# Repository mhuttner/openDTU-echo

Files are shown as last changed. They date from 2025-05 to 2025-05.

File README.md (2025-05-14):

# openDTU Echo

PCB for openDTU onBattery

This PCB can be easily ordered from JLCPCB with assembly, but the ESP32-S3 and the Ebyte E49-900M20S module need to be soldered by hand.

## Features

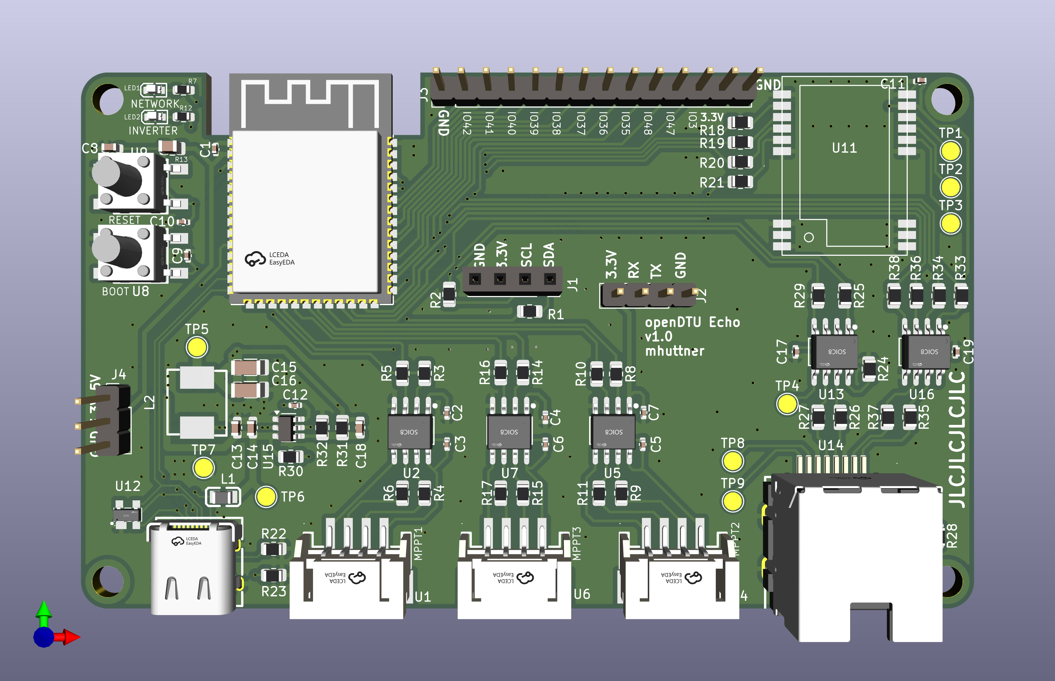
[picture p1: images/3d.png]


- ESP32-S3
- CMT2300A Chip in an Ebyte E49-900M20S module, NRF Chip is **not** supported
- Three ADUM1201 isolators with Ports for Victron VE.Direct Charge controllers / Smart Shunt
- SN65HVD230 CAN transceiver connected to RJ45 connector (Pin 4 and 5)
- ISL3178EIBZ RS485 transceiver connected to RJ45 connector (Pin 1 and 2)
- 3.3V Switching regulator based on the TPS54202DDC
- I2C Header for an OLED display

## Schematic

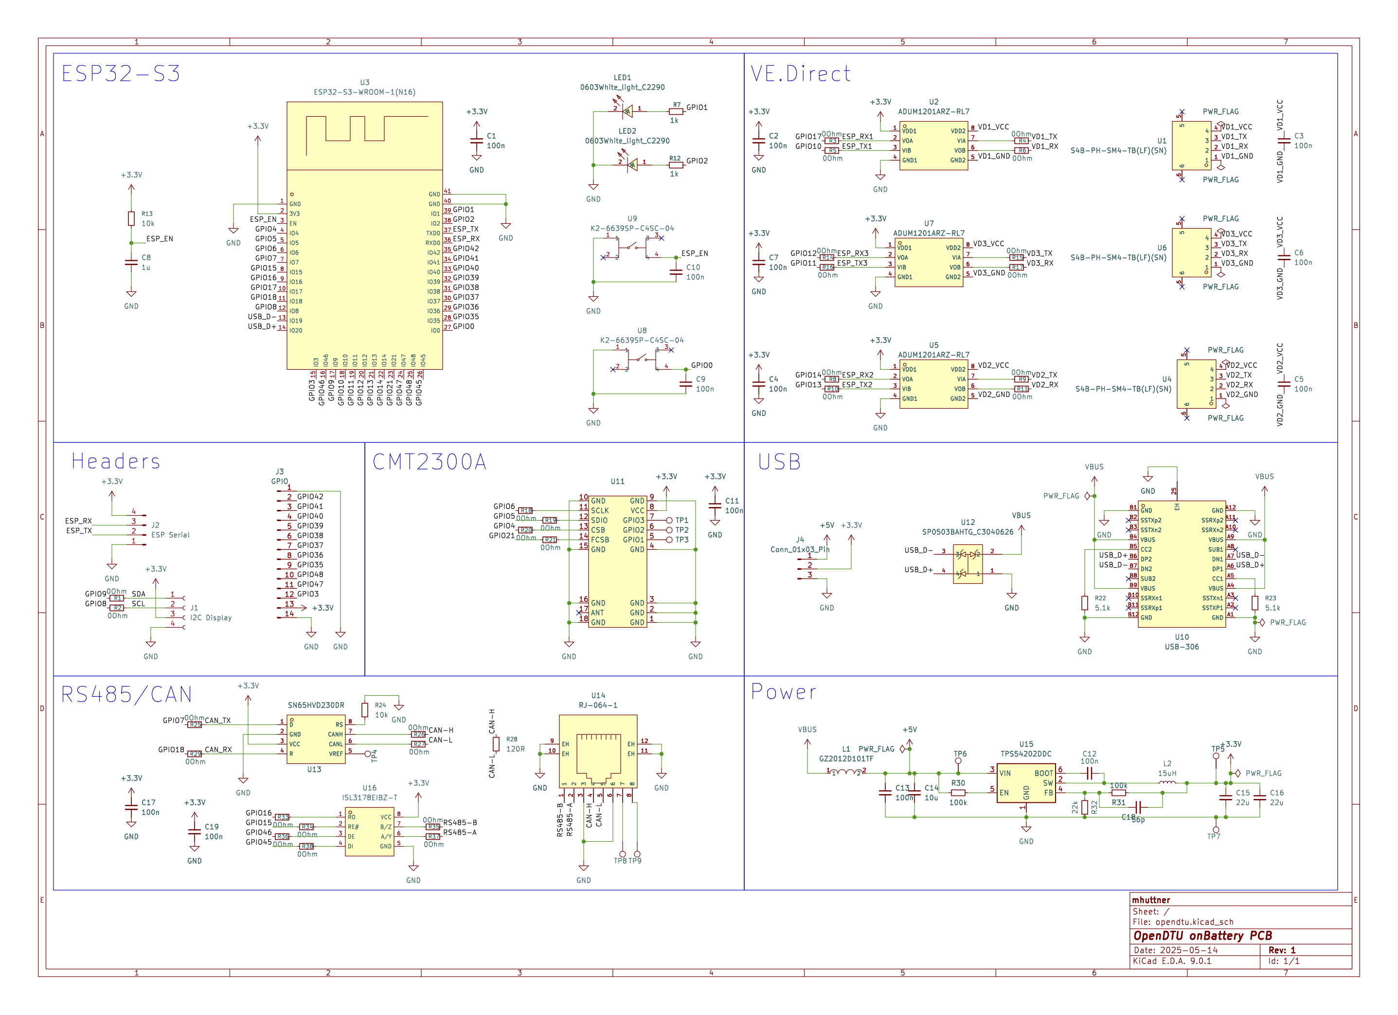
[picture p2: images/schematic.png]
Schematic


## PCB

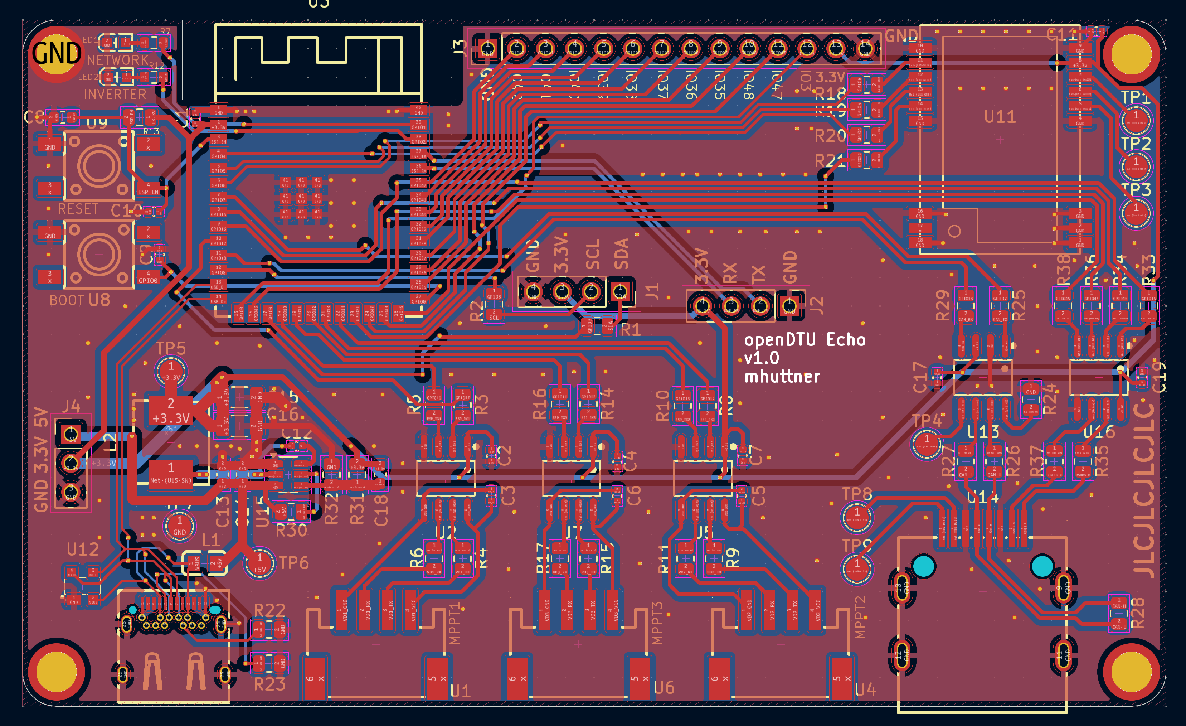
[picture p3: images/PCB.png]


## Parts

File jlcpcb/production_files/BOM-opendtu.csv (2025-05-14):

Comment | Designator | Footprint | LCSC | Quantity
GZ2012D101TF | L1 | L0805 | C1015 | 1
SN65HVD230DR | U13 | SOIC-8_L4.9-W3.9-P1.27-LS6.0-BL | C12084 | 1
22u | C15,C16 | C_1206_3216Metric | C12891 | 2
100n | C13 | C_0603_1608Metric | C14663 | 1
100k | R30,R31 | R_0805_2012Metric | C149504 | 2
100n | C1,C10,C11,C12,C17,C19,C2,C3,C4,C5,C6,C7,C9 | C_0402_1005Metric | C1525 | 13
1u | C8 | C_0603_1608Metric | C15849 | 1
56p | C18 | C_0603_1608Metric | C1676 | 1
10k | R13,R24 | C_0805_2012Metric | C17414 | 2
120R | R28 | R_0805_2012Metric | C17437 | 1
0Ohm | R1,R10,R11,R14,R15,R16,R17,R18,R19,R2,R20,R21,R25,R26,R27,R29,R3,R33,R34,R35,R36,R37,R38,R4,R5,R6,R8,R9 | R_0805_2012Metric | C17477 | 28
22k | R32 | R_0805_2012Metric | C17560 | 1
15uH | L2 | IND-SMD_L7.1-W6.6_SLO0618H | C182182 | 1
10u | C14 | C_0603_1608Metric | C19702 | 1
1k | R12,R7 | R_0603_1608Metric | C21190 | 2
0603White_light_C2290 | LED1,LED2 | LED0603-R-RD_WHITE | C2290 | 2
S4B-PH-SM4-TB(LF)(SN) | U1,U4,U6 | CONN-SMD_S4B-PH-SM4-TB-LF-SN | C265102 | 3
5.1k | R22,R23 | R_0805_2012Metric | C27834 | 2
ESP32-S3-WROOM-1(N16) | U3 | WIRELM-SMD_ESP32-S3-WROOM-1 | C2913199 | 1
SP0503BAHTG_C3040626 | U12 | SOT-143-4_L2.9-W1.3-P1.92-LS2.4-BL | C3040626 | 1
USB-306 | U10 | USB-TYPE-C-TH_USB-306. | C309338 | 1
ISL3178EIBZ-T | U16 | SOIC-8_L4.9-W3.9-P1.27-LS6.0-BL | C382015 | 1
RJ-064-1 | U14 | CONN-SMD_RJ-064 | C7205199 | 1
K2-6639SP-C4SC-04 | U8,U9 | KEY-SMD_4P-L6.0-W6.0-P3.90-LS9.0 | C83206 | 2
ADUM1201ARZ-RL7 | U2,U5,U7 | SOIC-8_L4.9-W3.9-P1.27-LS6.0-BL | C9669 | 3
TestPoint | TP1 | TestPoint_Pad_D2.0mm |  | 1
TestPoint | TP7 | TestPoint_Pad_D2.0mm |  | 1
TestPoint | TP9 | TestPoint_Pad_D2.0mm |  | 1
ESP Serial | J2 | PinHeader_1x04_P2.54mm_Vertical |  | 1
I2C Display | J1 | PinSocket_1x04_P2.54mm_Vertical |  | 1
TestPoint | TP3 | TestPoint_Pad_D2.0mm |  | 1
GPIO | J3 | PinHeader_1x14_P2.54mm_Vertical |  | 1
~ | U11 | E49-900M20S |  | 1
TestPoint | TP6 | TestPoint_Pad_D2.0mm |  | 1
Conn_01x03_Pin | J4 | PinHeader_1x03_P2.54mm_Vertical |  | 1
TestPoint | TP2 | TestPoint_Pad_D2.0mm |  | 1
TestPoint | TP4 | TestPoint_Pad_D2.0mm |  | 1
TestPoint | TP5 | TestPoint_Pad_D2.0mm |  | 1
TPS54202DDC | U15 | SOT-23-6 |  | 1
TestPoint | TP8 | TestPoint_Pad_D2.0mm |  | 1

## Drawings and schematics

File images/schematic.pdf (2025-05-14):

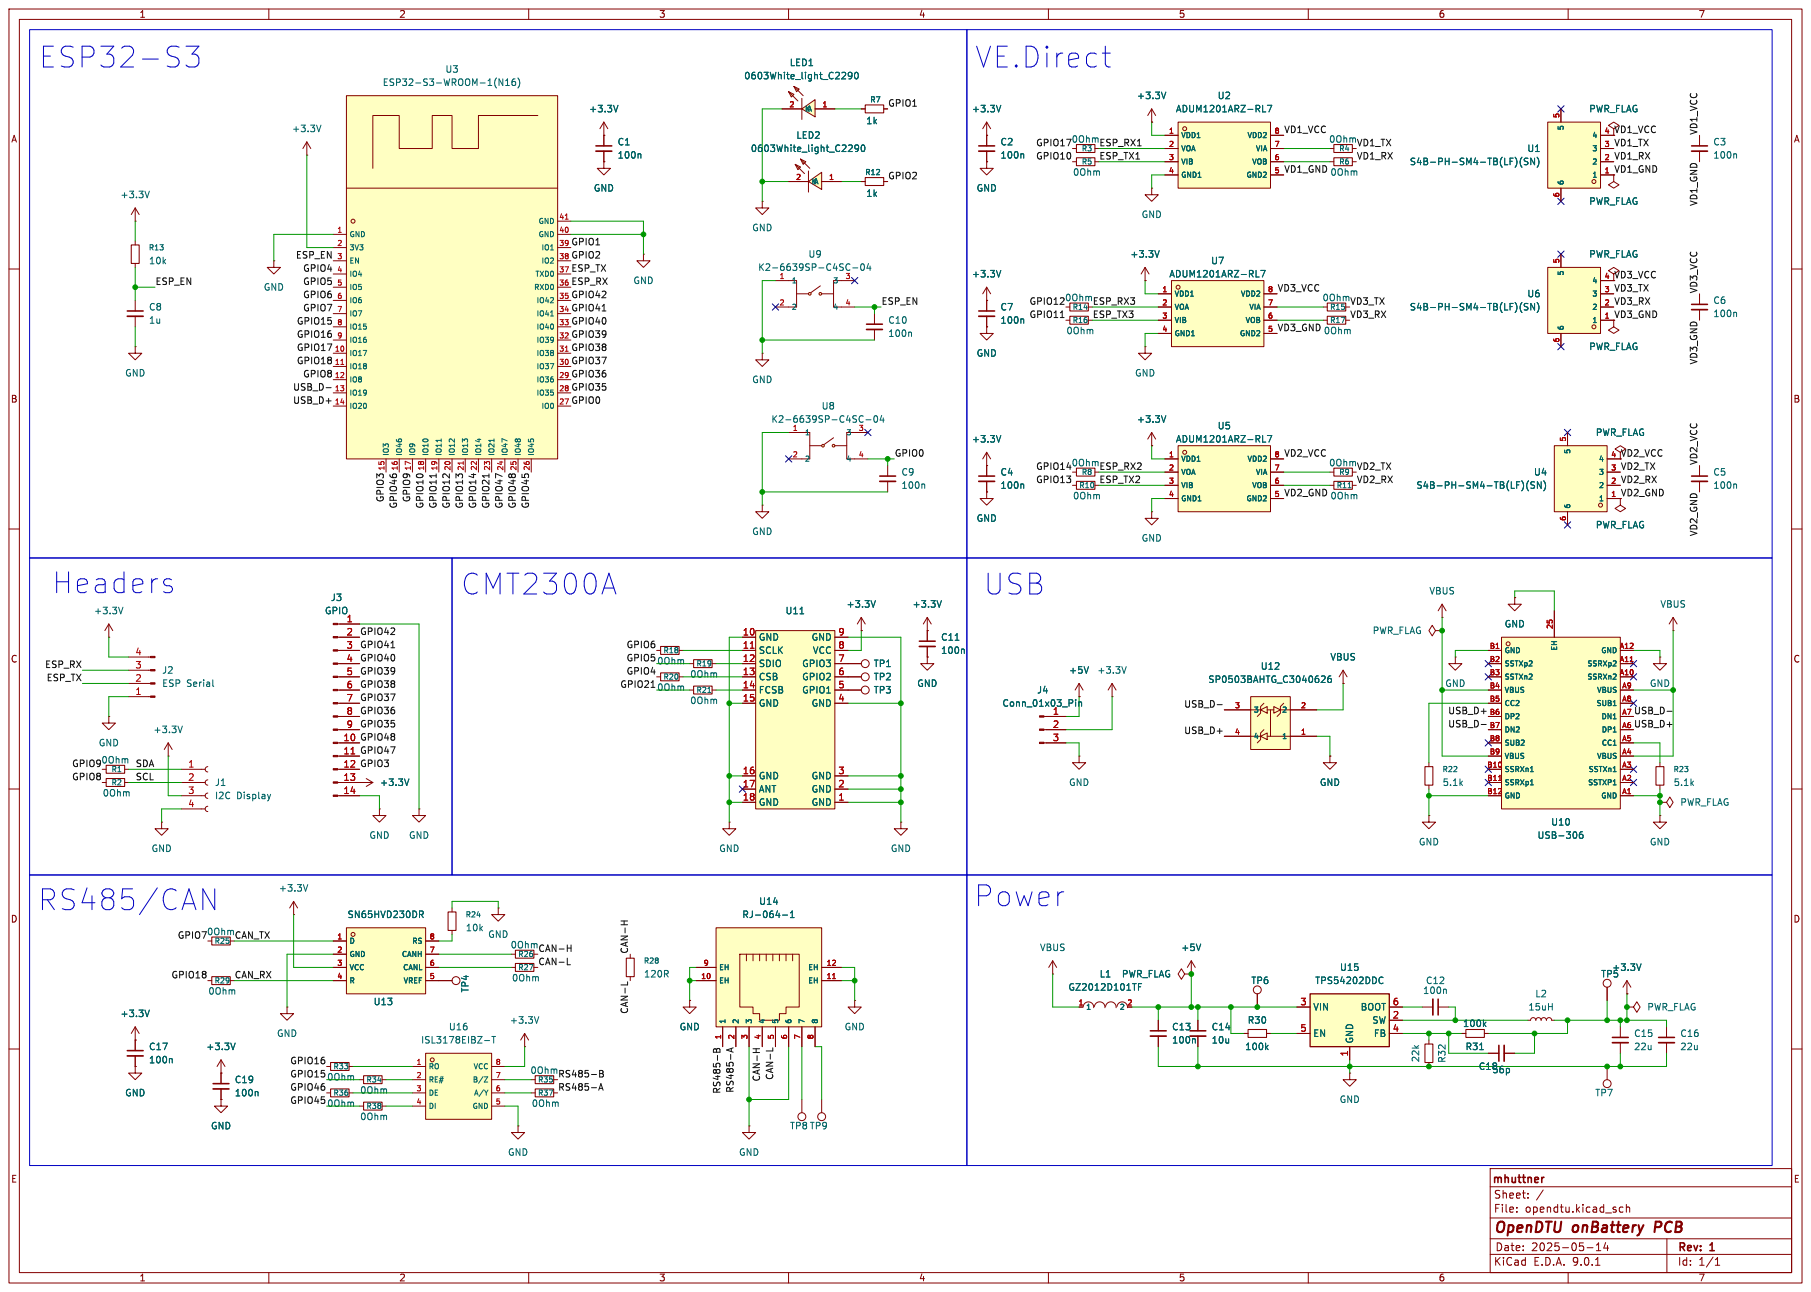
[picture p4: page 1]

5 U1 S4B-PH-SM4-TB(LF)(SN) PWR_FLAG

8 EH 12 EH 11 GND GND

8 EH 12 EH 11 U14 RJ-064-1 GND

1 BOOT 6 SW 2 FB 4 U15 TPS54202DDC GND

File: opendtu.kicad_sch Sheet: / mhuttner

Id: 1/1 OpenDTU onBattery PCB

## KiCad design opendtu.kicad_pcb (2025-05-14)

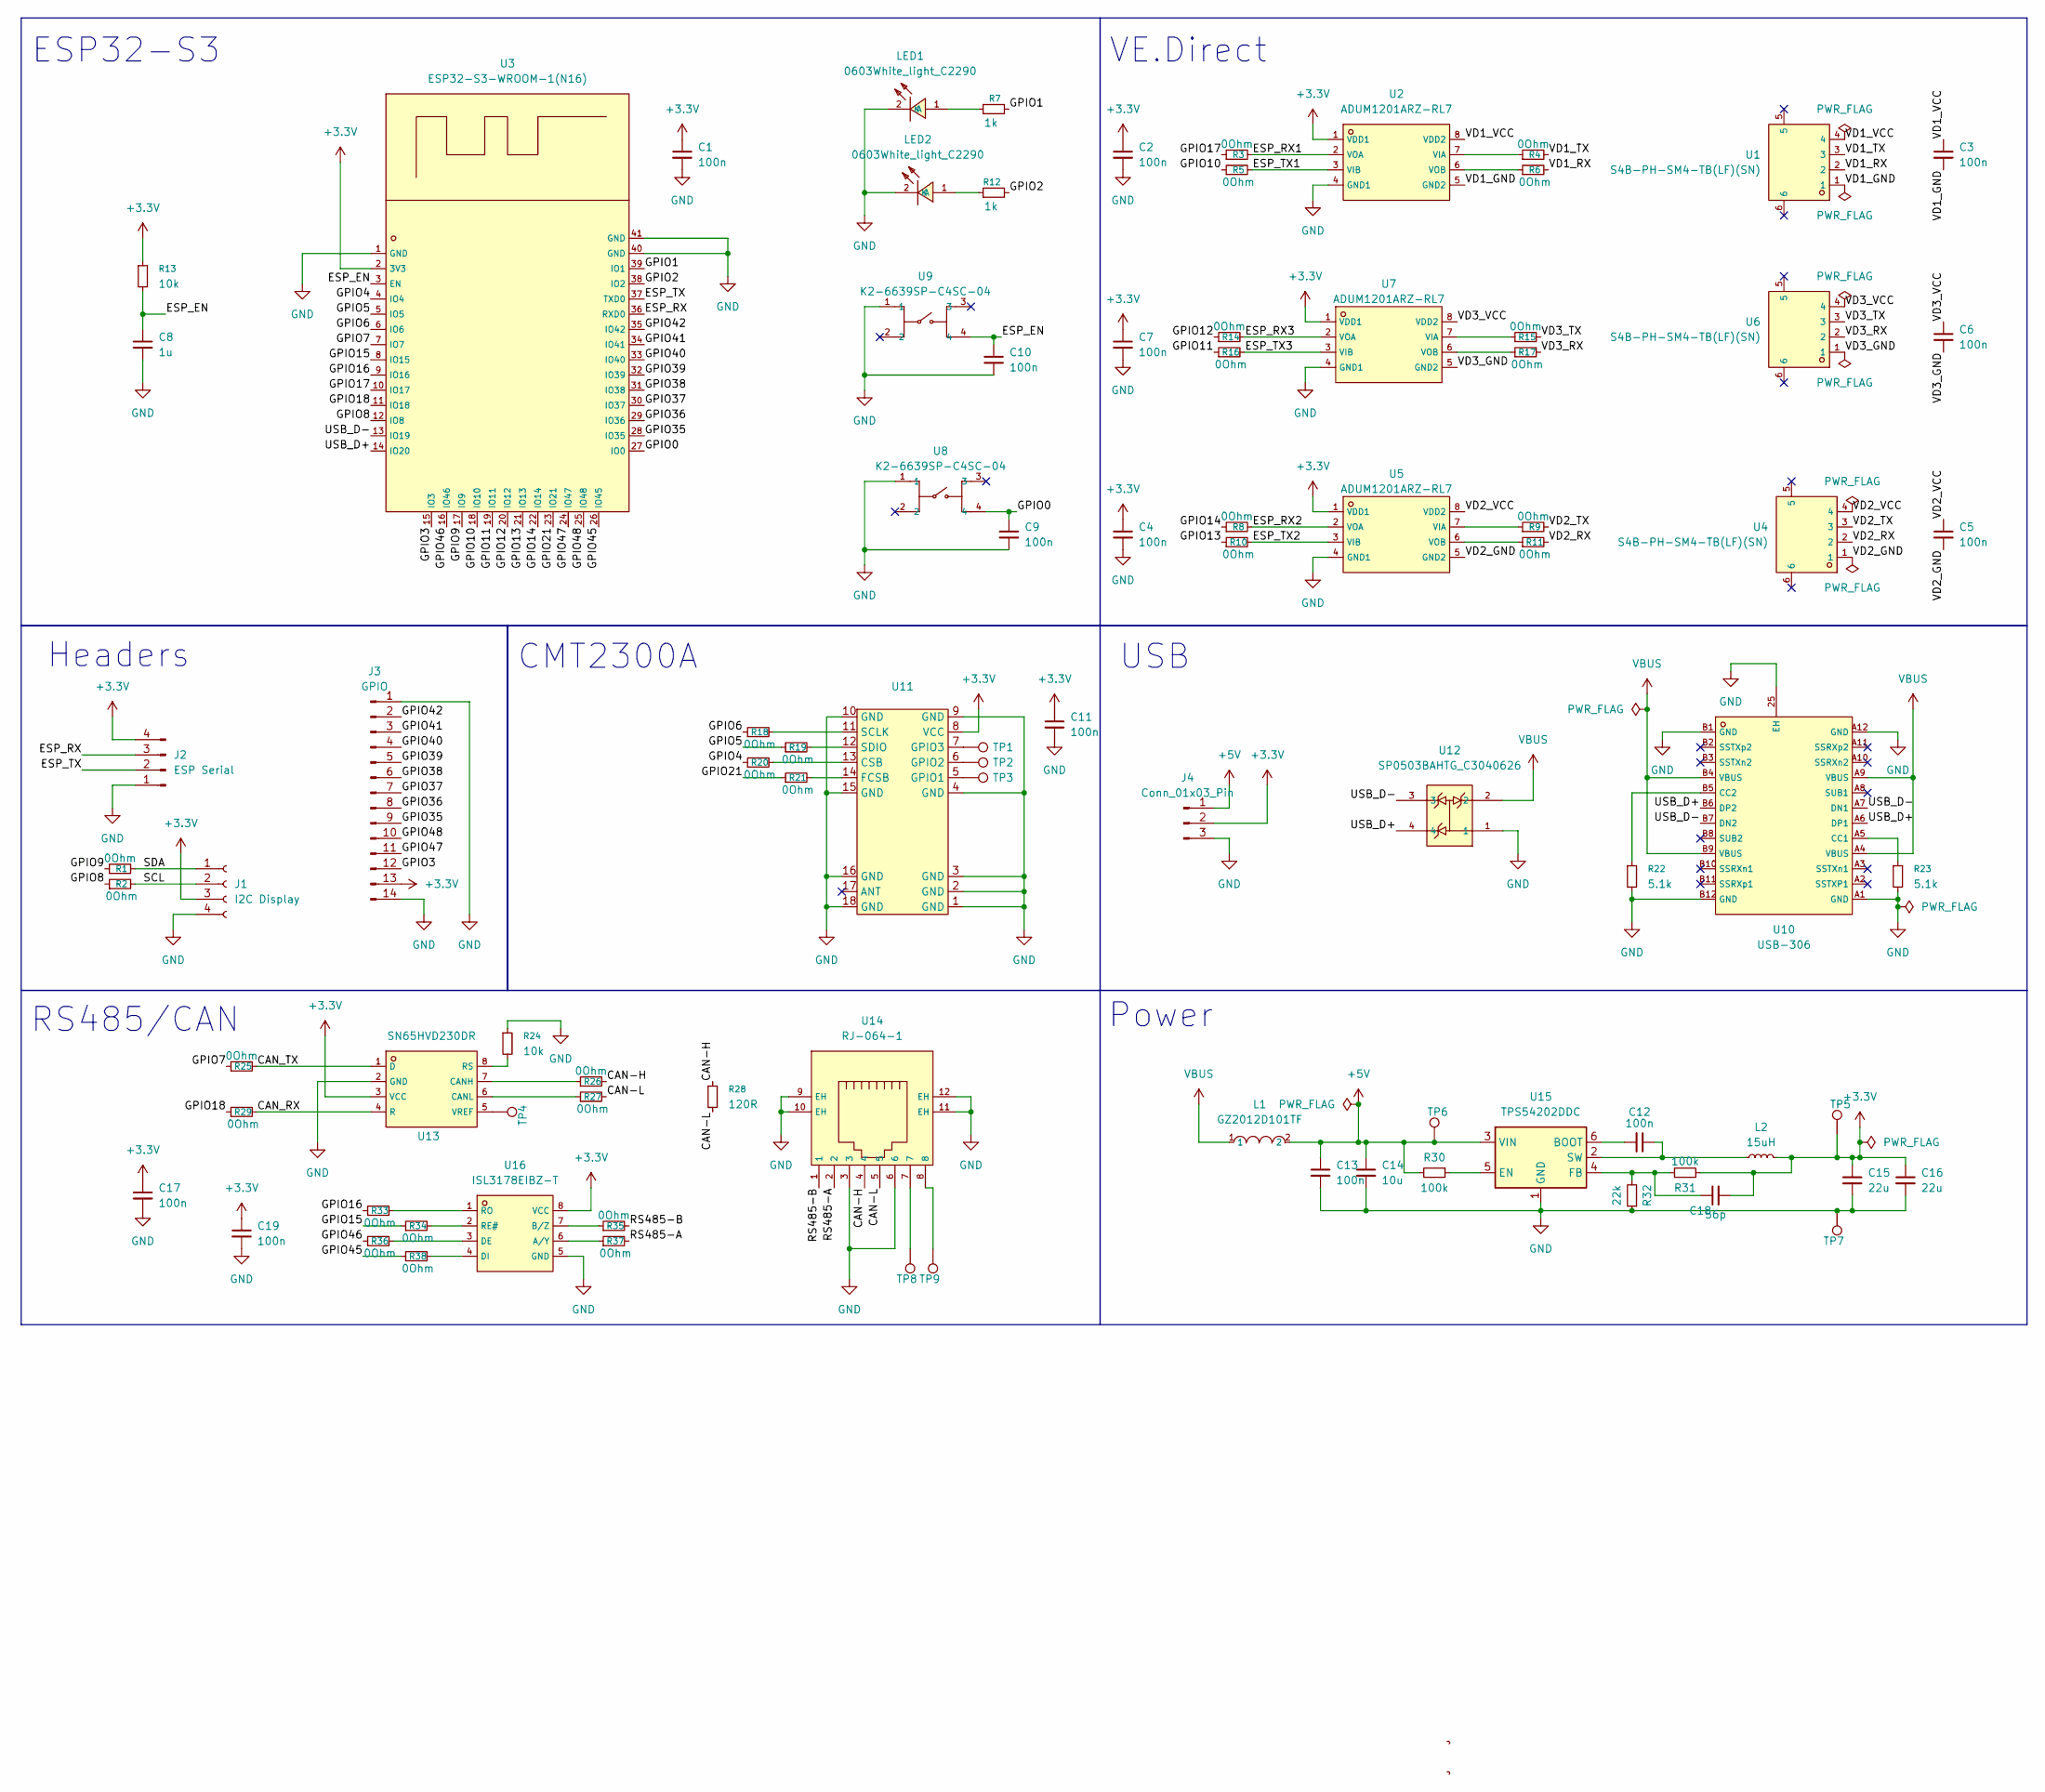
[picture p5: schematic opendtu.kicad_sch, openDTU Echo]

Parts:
C1, C2, C3, C4, C5, C6, C7, C9, C10, C11, C12, C17, C19: 100n; C_0402_1005Metric
C8: 1u; C_0603_1608Metric
C13: 100n; C_0603_1608Metric
C14: 10u; C_0603_1608Metric
C15, C16: 22u; C_1206_3216Metric
C18: 56p; C_0603_1608Metric
J1: I2C Display; PinSocket_1x04_P2.54mm_Vertical
J2: ESP Serial; PinHeader_1x04_P2.54mm_Vertical
J3: GPIO; PinHeader_1x14_P2.54mm_Vertical
J4: Conn_01x03_Pin; PinHeader_1x03_P2.54mm_Vertical
L1: GZ2012D101TF; L0805; LCSC C1015
L2: 15uH; IND-SMD_L7.1-W6.6_SLO0618H
LED1, LED2: 0603White_light_C2290; LED0603-R-RD_WHITE; LCSC C2290
R1, R2, R3, R4, R5, R6, R8, R9, R10, R11, R14, R15, R16, R17, R18, R19, R20, R21, R25, R26, R27, R29, R33, R34, R35, R36, R37, R38: 0Ohm; R_0805_2012Metric
R7, R12: 1k; R_0603_1608Metric
R13: 10k; C_0805_2012Metric
R22, R23: 5.1k; R_0805_2012Metric
R24: 10k; R_0805_2012Metric
R28: 120R; R_0805_2012Metric
R30, R31: 100k; R_0805_2012Metric
R32: 22k; R_0805_2012Metric
TP1, TP2, TP3, TP4, TP5, TP6, TP7, TP8, TP9: TestPoint; TestPoint_Pad_D2.0mm
U1, U4, U6: S4B-PH-SM4-TB(LF)(SN); CONN-SMD_S4B-PH-SM4-TB-LF-SN; LCSC C265102
U2, U5, U7: ADUM1201ARZ-RL7; SOIC-8_L4.9-W3.9-P1.27-LS6.0-BL; LCSC C9669
U3: ESP32-S3-WROOM-1(N16); WIRELM-SMD_ESP32-S3-WROOM-1; LCSC C2913199
U8, U9: K2-6639SP-C4SC-04; KEY-SMD_4P-L6.0-W6.0-P3.90-LS9.0; LCSC C83206
U10: USB-306; USB-TYPE-C-TH_USB-306.; LCSC C309338
U11: E49-900M20S
U12: SP0503BAHTG_C3040626; SOT-143-4_L2.9-W1.3-P1.92-LS2.4-BL; LCSC C3040626
U13: SN65HVD230DR; SOIC-8_L4.9-W3.9-P1.27-LS6.0-BL; LCSC C12084
U14: RJ-064-1; CONN-SMD_RJ-064; LCSC C7205199
U15: TPS54202DDC; SOT-23-6
U16: ISL3178EIBZ-T; SOIC-8_L4.9-W3.9-P1.27-LS6.0-BL; LCSC C382015

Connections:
+3.3V: C1.1, C2.1, C4.1, C7.1, C11.1, C15.1, C16.1, C17.1, C18.2, C19.1, J1.3, J2.4, J3.13, J4.2, L2.2, R13.1, R31.2, TP5.1, U2.1 (VDD1), U3.2 (3V3), U5.1 (VDD1), U7.1 (VDD1), U11.8 (VCC), U13.3 (VCC), U16.8 (VCC)
+5V: C13.1, C14.1, J4.1, L1.2, R30.2, TP6.1, U15.3 (VIN)
/CAN-H: R26.2, R28.1, U14.4
/CAN-L: R27.2, R28.2, U14.5
/CAN_RX: R29.2, U13.4 (R)
/CAN_TX: R25.2, U13.1 (D)
/ESP_EN: C8.1, C10.1, R13.2, U3.3 (EN), U9.4
/ESP_RX: J2.3, U3.36 (RXD0)
/ESP_RX1: R3.2, U2.2 (VOA)
/ESP_RX2: R8.2, U5.2 (VOA)
/ESP_RX3: R14.2, U7.2 (VOA)
/ESP_TX: J2.2, U3.37 (TXD0)
/ESP_TX1: R5.2, U2.3 (VIB)
/ESP_TX2: R10.2, U5.3 (VIB)
/ESP_TX3: R16.2, U7.3 (VIB)
/GPIO0: C9.1, U3.27 (IO0), U8.4
/GPIO1: R7.2, U3.39 (IO1)
/GPIO2: R12.2, U3.38 (IO2)
/GPIO3: J3.12, U3.15 (IO3)
/GPIO4: R20.1, U3.4 (IO4)
/GPIO5: R19.1, U3.5 (IO5)
/GPIO6: R18.1, U3.6 (IO6)
/GPIO7: R25.1, U3.7 (IO7)
/GPIO8: R2.1, U3.12 (IO8)
/GPIO9: R1.1, U3.17 (IO9)
/GPIO10: R5.1, U3.18 (IO10)
/GPIO11: R16.1, U3.19 (IO11)
/GPIO12: R14.1, U3.20 (IO12)
/GPIO13: R10.1, U3.21 (IO13)
/GPIO14: R8.1, U3.22 (IO14)
/GPIO15: R34.1, U3.8 (IO15)
/GPIO16: R33.1, U3.9 (IO16)
/GPIO17: R3.1, U3.10 (IO17)
/GPIO18: R29.1, U3.11 (IO18)
/GPIO21: R21.1, U3.23 (IO21)
/GPIO35: J3.9, U3.28 (IO35)
/GPIO36: J3.8, U3.29 (IO36)
/GPIO37: J3.7, U3.30 (IO37)
/GPIO38: J3.6, U3.31 (IO38)
/GPIO39: J3.5, U3.32 (IO39)
/GPIO40: J3.4, U3.33 (IO40)
/GPIO41: J3.3, U3.34 (IO41)
/GPIO42: J3.2, U3.35 (IO42)
/GPIO45: R38.1, U3.26 (IO45)
/GPIO46: R36.1, U3.16 (IO46)
/GPIO47: J3.11, U3.24 (IO47)
/GPIO48: J3.10, U3.25 (IO48)
/RS485-A: R37.2, U14.2
/RS485-B: R35.2, U14.1
/SCL: J1.2, R2.2
/SDA: J1.1, R1.2
/USB_D+: U3.14 (IO20), U10.A6 (DP1), U10.B6 (DP2), U12.4
/USB_D-: U3.13 (IO19), U10.A7 (DN1), U10.B7 (DN2), U12.3
/VD1_GND: C3.2, U1.1, U2.5 (GND2)
/VD1_RX: R6.2, U1.2
/VD1_TX: R4.2, U1.3
/VD1_VCC: C3.1, U1.4, U2.8 (VDD2)
/VD2_GND: C5.2, U4.1, U5.5 (GND2)
/VD2_RX: R11.2, U4.2
/VD2_TX: R9.2, U4.3
/VD2_VCC: C5.1, U4.4, U5.8 (VDD2)
/VD3_GND: C6.2, U6.1, U7.5 (GND2)
/VD3_RX: R17.2, U6.2
/VD3_TX: R15.2, U6.3
/VD3_VCC: C6.1, U6.4, U7.8 (VDD2)
GND: C1.2, C2.2, C4.2, C7.2, C8.2, C9.2, C10.2, C11.2, C13.2, C14.2, C15.2, C16.2, C17.2, C19.2, J1.4, J2.1, J3.1, J3.14, J4.3, LED1.2 (K), LED2.2 (K), R22.2, R23.2, R24.1, R32.1, TP7.1, U2.4 (GND1), U3.1 (GND), U3.40 (GND), U3.41 (GND), U5.4 (GND1), U7.4 (GND1), U8.1, U9.1, U10.25 (EH), U10.A1 (GND), U10.A12 (GND), U10.B1 (GND), U10.B12 (GND), U11.1 (GND), U11.2 (GND), U11.3 (GND), U11.4 (GND), U11.9 (GND), U11.10 (GND), U11.15 (GND), U11.16 (GND), U11.18 (GND), U12.1, U13.2 (GND), U14.3, U14.6, U14.9 (EH), U14.10 (EH), U14.11 (EH), U14.12 (EH), U15.1 (GND), U16.5 (GND)
unnamed: LED1.1 (A), R7.1
unnamed: LED2.1 (A), R12.1
unnamed: TP8.1, U14.7
unnamed: TP9.1, U14.8
unnamed: R4.1, U2.7 (VIA)
unnamed: R6.1, U2.6 (VOB)
unnamed: R9.1, U5.7 (VIA)
unnamed: R11.1, U5.6 (VOB)
unnamed: R15.1, U7.7 (VIA)
unnamed: R17.1, U7.6 (VOB)
unnamed: R23.1, U10.A5 (CC1)
unnamed: R22.1, U10.B5 (CC2)
unnamed: R20.2, U11.13 (CSB)
unnamed: R21.2, U11.14 (FCSB)
unnamed: TP3.1, U11.5 (GPIO1)
unnamed: TP2.1, U11.6 (GPIO2)
unnamed: TP1.1, U11.7 (GPIO3)
unnamed: R18.2, U11.11 (SCLK)
unnamed: R19.2, U11.12 (SDIO)
unnamed: R26.1, U13.7 (CANH)
unnamed: R27.1, U13.6 (CANL)
unnamed: R24.2, U13.8 (RS)
unnamed: TP4.1, U13.5 (VREF)
unnamed: C12.2, U15.6 (BOOT)
unnamed: R30.1, U15.5 (EN)
unnamed: C18.1, R31.1, R32.2, U15.4 (FB)
unnamed: C12.1, L2.1, U15.2 (SW)
unnamed: R37.1, U16.6 (A/Y)
unnamed: R35.1, U16.7 (B/Z)
unnamed: R36.2, U16.3 (DE)
unnamed: R38.2, U16.4 (DI)
unnamed: R34.2, U16.2 (RE#)
unnamed: R33.2, U16.1 (RO)
VBUS: L1.1, U10.A4 (VBUS), U10.A9 (VBUS), U10.B4 (VBUS), U10.B9 (VBUS), U12.2

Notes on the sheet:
ESP32-S3
VE.Direct
Headers
RS485/CAN
CMT2300A
Power
USB

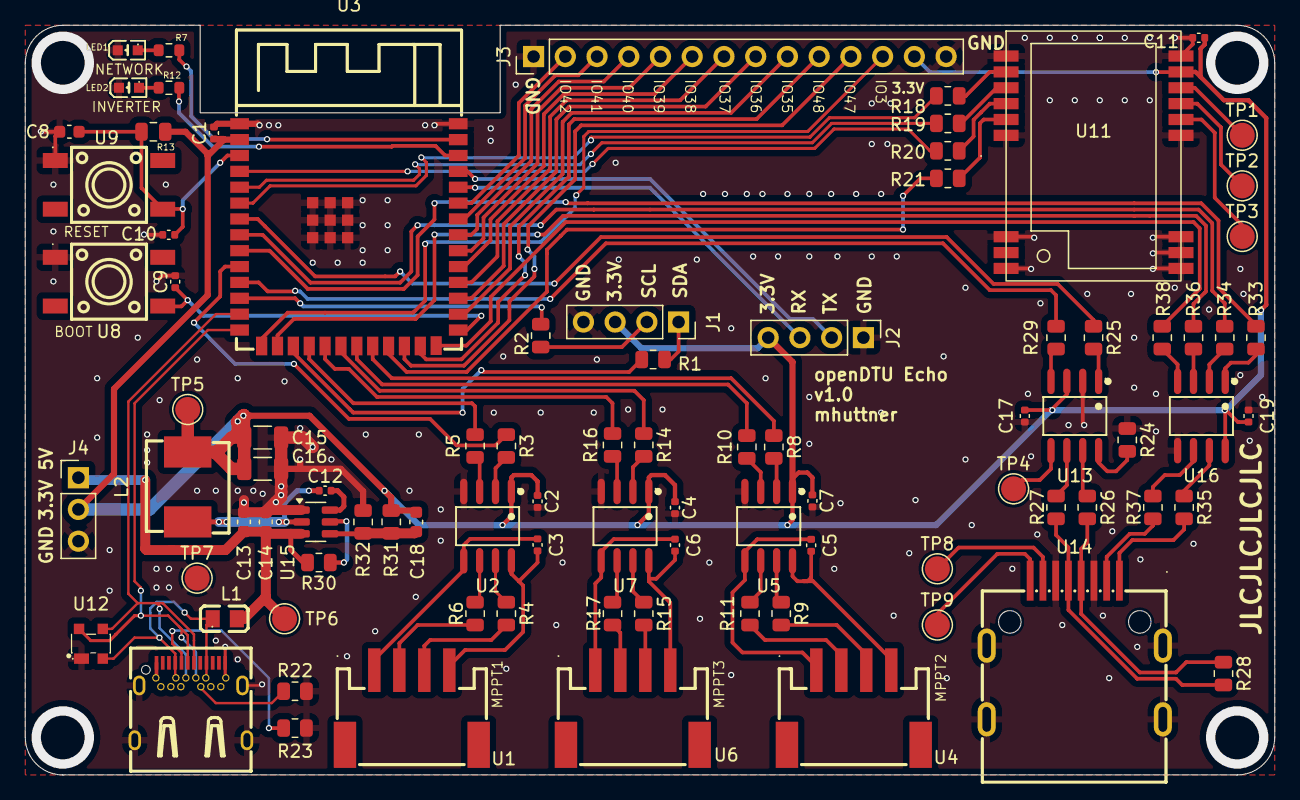
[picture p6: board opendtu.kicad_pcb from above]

Board: 2 copper layers, 100.0 x 60.0 mm, 90 parts (0 on the bottom side), 100 nets.
